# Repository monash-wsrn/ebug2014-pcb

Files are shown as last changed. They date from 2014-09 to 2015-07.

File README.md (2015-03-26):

ebug2014-pcb
============
- Created with Altium Designer
- Open entire project via "eBug2014.DsnWrk"

#Important
If repouring the *Mid-Layer 1* GND polygon, please do the following in order to preserve the hatched grounds under the touch switches:  
1) Move the arc (ring shape) around each button on *Mid-Layer 1* to any other layer  
2) Repour the *Mid-Layer 1* GND polygon  
3) Restore the arcs back to *Mid-Layer 1* and set their nets to GND

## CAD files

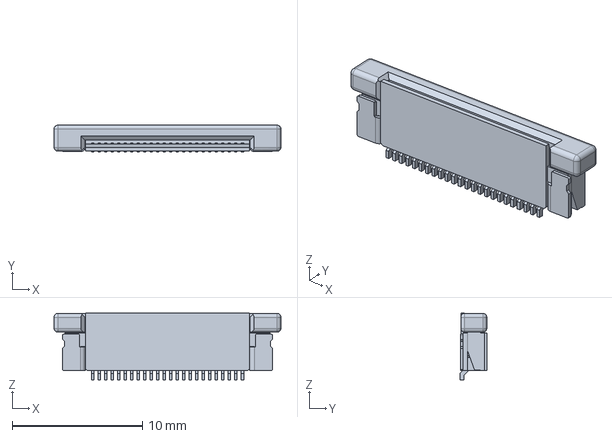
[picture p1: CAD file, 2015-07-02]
3D Models/c-2-1734592-4-c-3d.stp
17.4 x 2.05 x 5.11 mm

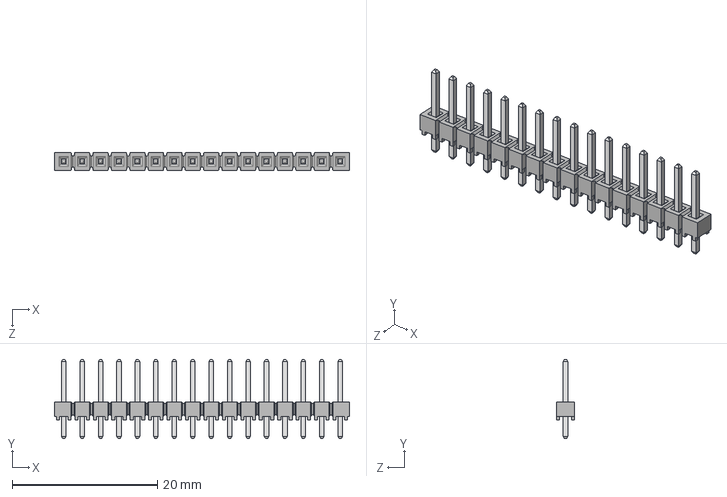
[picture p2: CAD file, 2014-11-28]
Documents/Parts/16-Pos Square Post Header/Samtec-TSW-116-07-T-S.step
40.6 x 10.9 x 2.54 mm

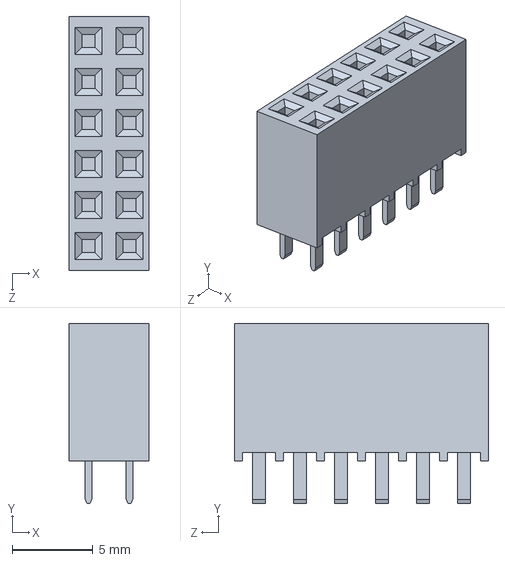
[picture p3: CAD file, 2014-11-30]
Documents/Parts/2x6 Way Socket/SSW-106-01-X-D.step
4.95 x 11.2 x 15.7 mm

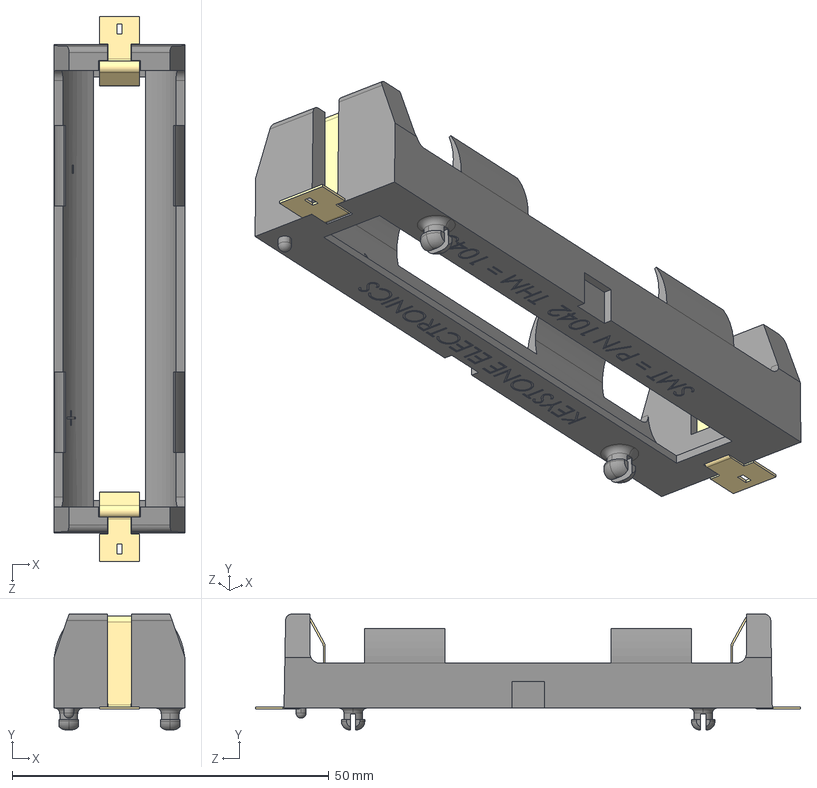
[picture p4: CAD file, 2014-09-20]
Documents/Parts/Battery Holder/1042/keystone-PN1042.STEP
20.7 x 18.3 x 86.0 mm

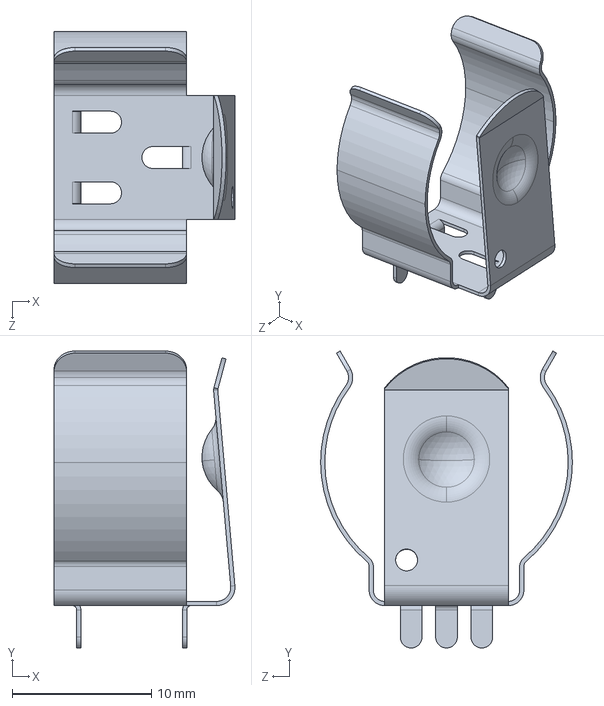
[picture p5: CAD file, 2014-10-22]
Documents/Parts/Battery Holder/54/keystone-PN54.STEP
13.0 x 21.4 x 18.1 mm

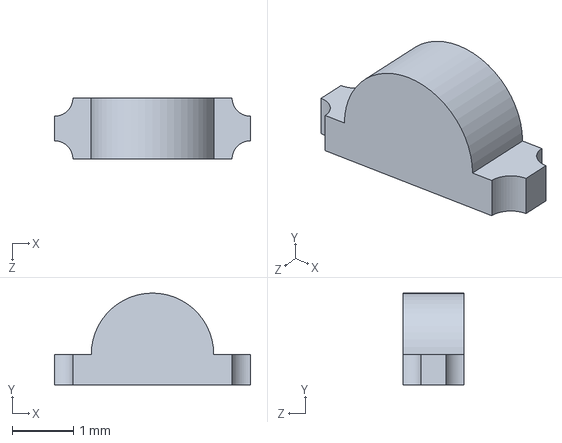
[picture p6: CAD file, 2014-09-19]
Documents/Parts/RGB LED (Side)/OVSRRGBCC3_step214.STEP
3.20 x 1.50 x 1 mm

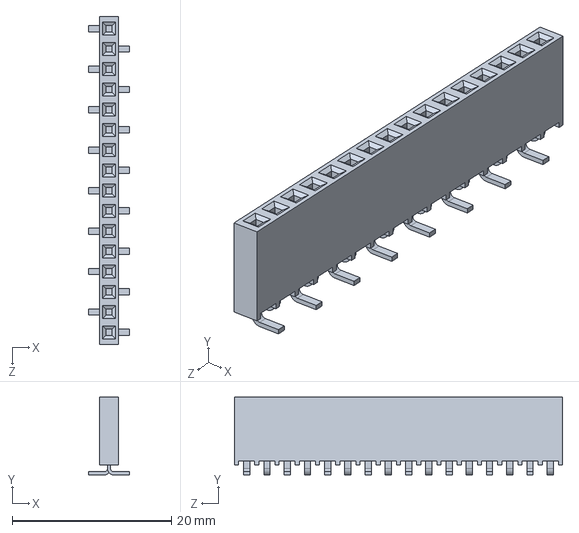
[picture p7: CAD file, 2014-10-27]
Documents/Parts/SMD 16-Pos Socket/Samtec-SSW-116-22-F-S-VS.step
5.16 x 9.78 x 41.1 mm

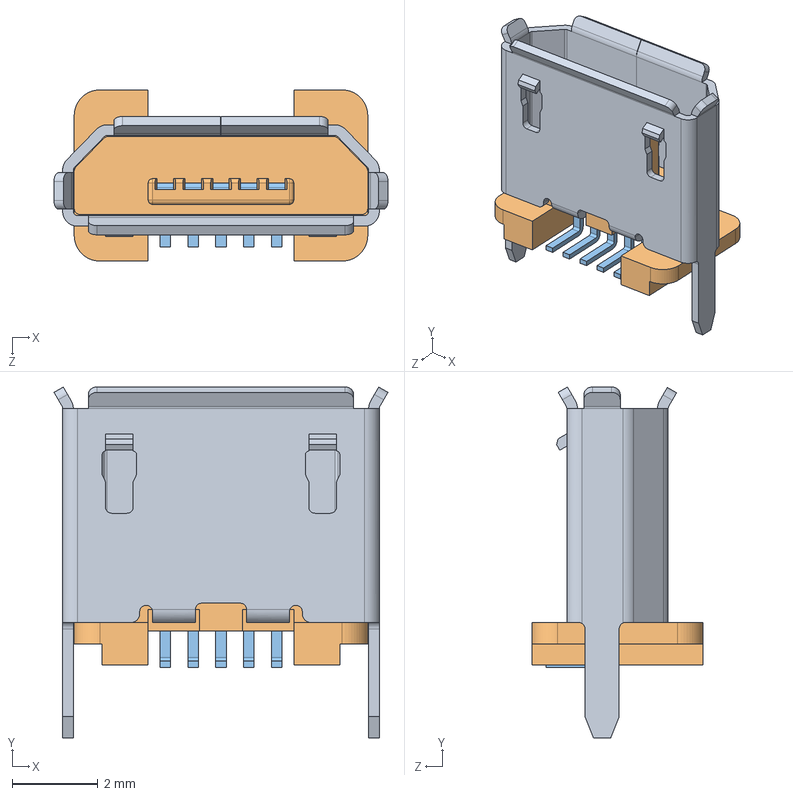
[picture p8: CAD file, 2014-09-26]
Documents/Parts/USB Micro-B Socket/USB3140-30-0170-1-X_revB.step
7.80 x 8.20 x 4.00 mm
HOUSING-2
TER2-14
TER2-11
TER2-13
TER2-12
TER2-10

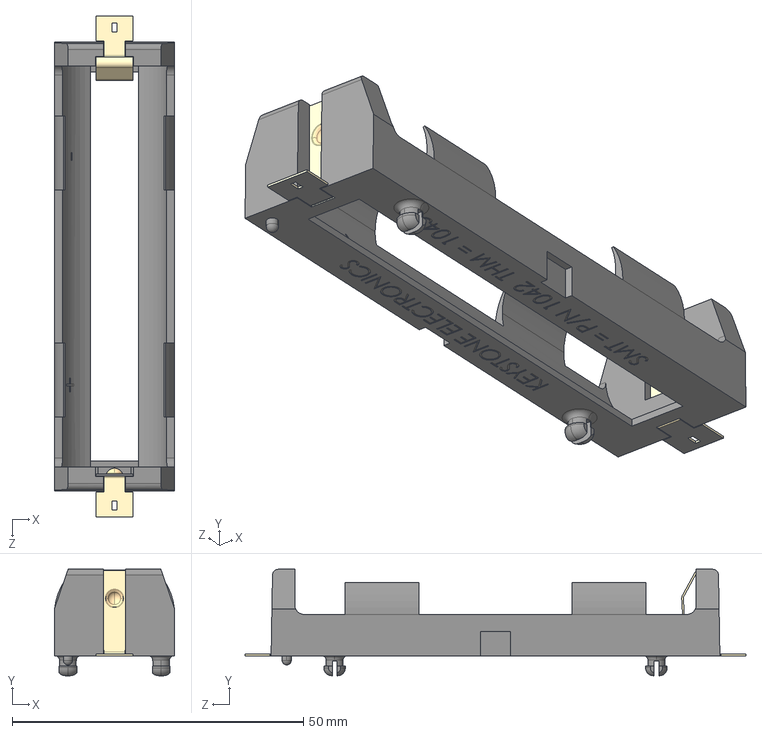
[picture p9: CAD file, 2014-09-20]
Documents/Parts/Battery Holder/1042/keystone-PN1042P.STEP
20.7 x 18.3 x 86.0 mm

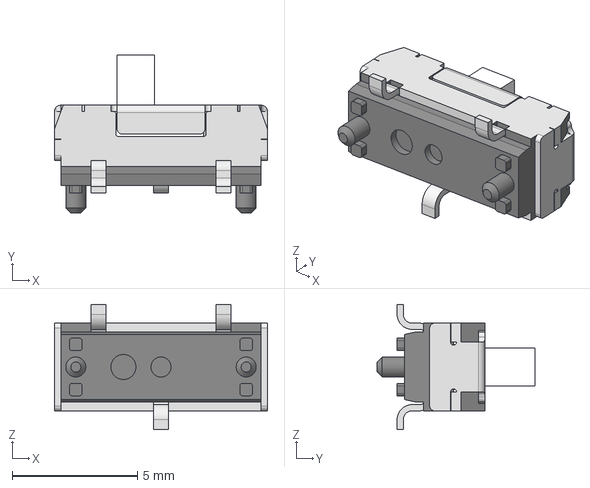
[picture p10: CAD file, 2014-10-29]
3D Models/CL-SB-12B-01T_2_14b.stp
8.50 x 6.30 x 5.00 mm
_12B-01_c
_2Top setting_s

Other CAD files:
3D Models/USB3140-30-0170-1-X_revB.STEP

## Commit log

2014-09-19 Initial commit of blank Altium project.
    [Axial Lead Diode.PcbLib, BGA_Rect.PcbLib, BGA_Sq_150P.PcbLib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]
2014-09-19 Add footprints and schematic symbols for RGB LED, Dual NFET and Triple SPDT Switch parts.
    [LEDs.SchDoc, OVSRRGBCC3_step214.STEP, PSoC.SchDoc]
2014-09-20 LED circuitry (schematic + layout) complete.
    [LED Circuit.PrjPcb, LED Circuit.SchDoc, LED1-2.SchDoc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]
2014-09-20 Add outjob file and PDF.
    [PCB.PcbDoc, eBug2014.PrjPcb]
2014-09-20 Simplify LED circuit. Updated PDF.
    [LED Circuit (Version 2).PrjPcb, LED Circuit (Version 2).SchDoc, LED Circuit.SchDoc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]
2014-09-22 Changed top mount RGB. Added battery holder to design (including 3D model). Added 4x mounting holes in PCB. Added empty schematic files for other circuitry.
    [DC Motors.SchDoc, LED Circuit (Version 2).SchDoc, LED1-4.SchDoc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]
2014-09-23 Add light sensor circuitry. Add DC motor circuitry. Add datasheets for light sensors and other new parts.
    [DC Motors.SchDoc, LED1-4.SchDoc, LED13-16.SchDoc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]
2014-09-23 Change light sensor output resistors to non-BOM (non-populated) parts.
    [Light Sensors.SchDoc, PCB.PcbDoc, PSoC.SchDoc]
2014-09-23 Add more detailed part information.
    [DC Motors.SchDoc, LED Circuit (Version 2).SchDoc, LED1-4.SchDoc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]
2014-09-25 Add additional part datasheets. Add required 3rd-party libraries. Add power supply circuitry (boost converters + battery charger).
    [DC Motors.SchDoc, LED1-4.SchDoc, Light Sensors.SchDoc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]
2014-09-26 Power supply circuit complete (schematic).
    [Light Sensors.SchDoc, PCB.PcbDoc, Power Supply.SchDoc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]
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2014-09-30 Power supply PCB routing complete.
    [DC Motors.SchDoc, LEDs.SchDoc, PCB.PcbDoc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]
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2014-10-27 Add LCD socket. Add datasheets for LCD and socket. Begin routing of PSoC nets.
    [DC Motors.SchDoc, LCD.SchDoc, LED1-4.SchDoc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]
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2014-10-29 Add Hall effect sensors (x4). Add power switch and reverse polarity protection PFET. Route LCD.
    [CL-SB-12B-01T_2_14b.stp, DC Motors.SchDoc, LCD.SchDoc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]
2014-10-30 Removed resistors from Hall effect sensor outputs. Added extra PFET for power switch. Removed D-/D+ connection to USB socket. Updated PDF.
    [DC Motors.SchDoc, LCD.SchDoc, Light Sensors.SchDoc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]
2014-11-23 Added additional nets to connect to PSoC: 12V_FB, PROG. Removed 10k pull-ups from STAT1/STAT2/PG signals (unneeded).
    [Light Sensors.SchDoc, PCB.PcbDoc, PSoC.SchDoc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]
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2014-11-26 Connect PSoC reset signals together. Make analog ground = digital ground (single ground design).
    [PCB.PcbDoc, PSoC.SchDoc]
2014-11-27 Added PSoC decoupling caps to PCB. Routed PSoC grounds and power. Updated PDF.
    [PCB.PcbDoc, PSoC.SchDoc]
2014-11-27 Added 10k series resistors to HE sensor outputs. Routed HE sensors on PCB. Connected charger PROG to PSoC IDAC.
    [DC Motors.SchDoc, PCB.PcbDoc, PSoC.SchDoc]
2014-11-27 Updated PDF. Moved some P2P signals to free up Analog pins on Port0 of top PSoC. Moved charger PROG to IDAC0. Added bypass caps to Port0[2] on both PSoCs.
    [PCB.PcbDoc, PSoC.SchDoc]
2014-11-28 Connect Bump Sensors. Add 3.3V regulator. Update PDF.
    [Bump Sensors.SchDoc, DC Motors.SchDoc, LCD.SchDoc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]
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2014-11-28 Create 3D model for LCD. Add ground polygon on top layer. Add resistor divider to scale battery voltage to interface to PSoC.
    [LCD.SchDoc, Light Sensors.SchDoc, PCB.PcbDoc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]
2014-11-28 Update PDF. Convert to 4-layer PCB. Add 4x2 header for Wireless module - connect to PSoC.
    [PSoC.SchDoc, Wireless.SchDoc]
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2014-11-30 Update PDF. Add 12V rail to Expansion Header.
    [Expansion Header.SchDoc, PSoC.SchDoc]
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2014-11-30 Add variant for light sensor part + output resistors. Update PDF.
    [Light Sensors.SchDoc, PSoC.SchDoc, eBug2014.PrjPcb]
2014-11-30 Fix capacitor voltage values.
    [DC Motors.SchDoc, Light Sensors.SchDoc, PSoC.SchDoc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]
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2014-12-03 Changed boost converter parts. Add new datasheets for boost converter, diode and inductor. Update PDF.
    [Bump Sensors.SchDoc, DC Motors.SchDoc, Expansion Header.SchDoc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]
2014-12-03 Fix 10uF cap footprint (motor circuit). Updated PDF.
    [DC Motors.SchDoc, Power Supply.SchDoc]
2014-12-14 Added 2x cap sense pads. Added test points. Added component designators. Added some informative text to overlays. Updated PDF.
    [PSoC.SchDoc, Power Supply.SchDoc, eBug2014.PrjPcb]
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2014-12-18 Fix USB socket pads (enlarged so they can be manufactured). Change R53 to 470k (previously was 500k). Updated PDF.
    [PSoC.SchDoc, Power Supply.SchDoc, eBug2014.PrjPcb]
2015-02-18 Bump project to Revision B. Modify silkscreen text containing names of designers. Move 2x drill holes next to LCD 2mm in x-direction closer to board edge.
    [Bump Sensors.SchDoc, DC Motors.SchDoc, Expansion Header.SchDoc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]
2015-02-18 Swap R53 and R54 values (ADC resistor divider).
    [PSoC.SchDoc]
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2015-02-18 Swap P0[2] and P0[4] for both PSOCs.
    [PSoC.SchDoc]
2015-03-23 Add integrated library containing LM3668. Reduce size of silkscreen box around designer names on PCB.
    [eBug2014.PrjPcb]
2015-03-23 Change 5V boost converter to LM3668. Add 5V boost inductor datasheet (Coilcraft LPS4018).
    [PSoC.SchDoc, Power Supply.SchDoc]
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2015-03-24 Swap 5V REG MODE SYNC pin with STAT1.
    [PSoC.SchDoc]
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2015-03-25 Do pin swaps to ensure light sensors are not on PSoC SIOs.
    [PSoC.SchDoc]
2015-03-25 Optimize positions of touch switches. Fix test-point labels for Side/Top LED Enable signals (wrong way around).
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2015-03-26 Replace bump sensor headers with single 8-pin header. Bump sensors are now numbered from 1 to 6 (instead of their position).
    [Bump Sensors.SchDoc, Expansion Header.SchDoc, PSoC.SchDoc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]
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2015-03-26 Add part number for 8-way bump sensor header. Update PDF.
    [Bump Sensors.SchDoc, PSoC.SchDoc, eBug2014.PrjPcb]
2015-03-30 Change 4x 0.2mm vias to 12mil hole size (under 5V reg). Update PDF.
    [eBug2014.PrjPcb]
2015-05-28 Add Pin 1 indicator on top silkscreen for U3. Update PDF.
    [eBug2014.PrjPcb]
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2015-06-30 Add 3x fiducial markers. Change light sensors to SMD parts (remove accompanying capacitors and resistors). Remove PDF doc (this will be added to the release). Fix RGB LED pin names (B and R were wron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
    [LCD.SchDoc, LED1-4.SchDoc, LED13-16.SchDoc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]
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2015-07-02 Change FFC connector. Add battery sense resistor. Add datasheet and 3D model for new FFC connector.
    [Expansion Header.SchDoc, PSoC.SchDoc, Power Supply.SchDoc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]
2015-07-10 Widen battery via/hole to polygon connections (from 0.2mm to 0.5mm). Bump to Rev D.
    [Bump Sensors.SchDoc, DC Motors.SchDoc, Expansion Header.SchDoc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]
2015-07-19 Fix comments in Power Supply schematic sheet - component designators were incorrect.
    [Power Supply.SchDoc]
